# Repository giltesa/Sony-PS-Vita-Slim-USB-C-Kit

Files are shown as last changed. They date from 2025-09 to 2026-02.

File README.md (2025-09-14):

# Sony PS Vita Slim USB-C Kit

The **Sony PS Vita Slim: USB-C Kit** is a board that allows to replace the original charging connector for a modern and standard **USB-C**.

**If your original connector is too old or damaged** and you need a new one, or **if you would like to charge your Sony PS Vita Slim with a standard USB-C charger**, like the charger of your phone, laptop, you can with this board.

This board is compatible with this model:

*   Sony PS Vita Slim

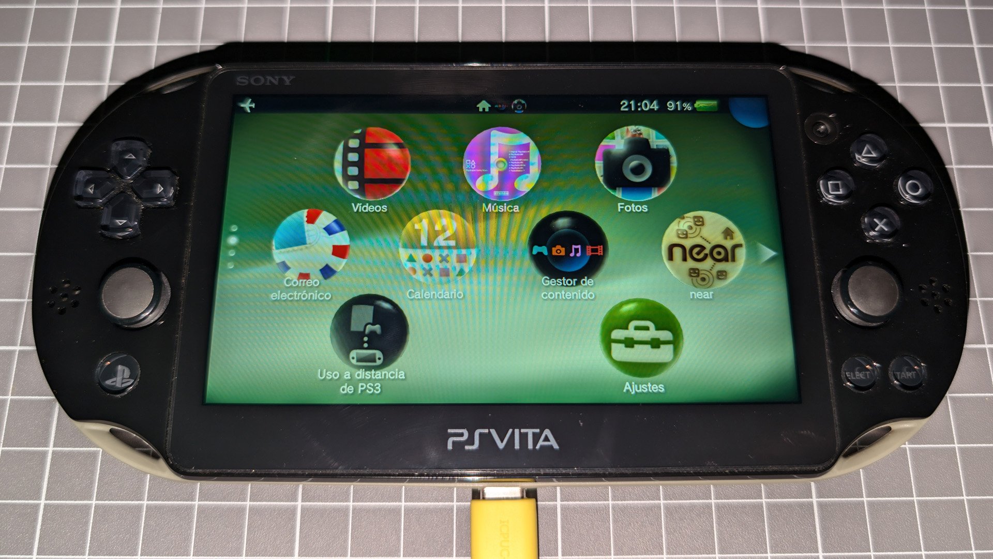
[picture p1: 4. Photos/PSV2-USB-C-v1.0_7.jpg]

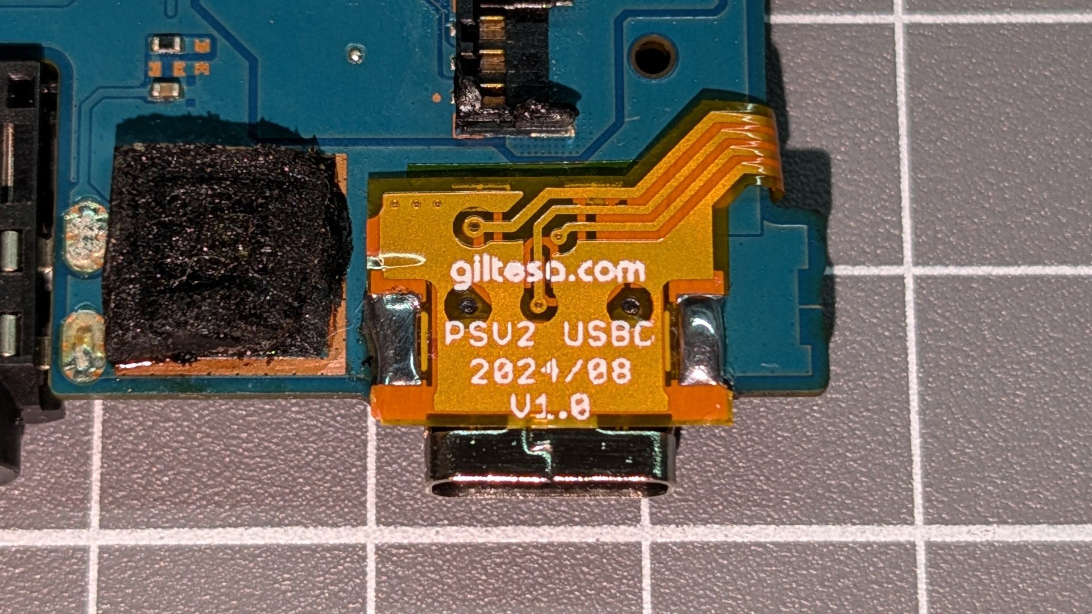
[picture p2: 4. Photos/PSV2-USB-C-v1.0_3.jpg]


## Would you like it?

https://shop.giltesa.com/product/sony-ps-vita-slim-usb-c-kit/

## More

- [giltesa.com](https://giltesa.com "giltesa.com")
- [twitter.com](https://twitter.com/giltesa "twitter.com")

## License

This project is licensed under a **Creative Commons** license:
**[Attribution-NonCommercial-ShareAlike 4.0 International (CC BY-NC-SA 4.0) ](https://creativecommons.org/licenses/by-nc-sa/4.0/)**

Check the [LICENSE.md](LICENSE.md) for more information.

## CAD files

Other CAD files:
2. Renders, 3D models/PCB v1.0.skp
2. Renders, 3D models/PCB v1.2.skp

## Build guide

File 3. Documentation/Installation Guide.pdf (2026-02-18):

# USB-C KIT For

# Sony PS VITA SLIM

### PRODUCT

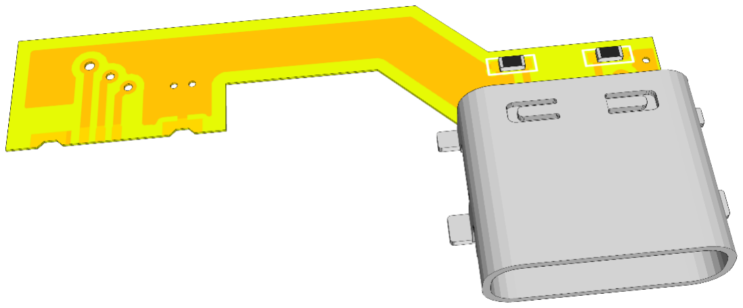
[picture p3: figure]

HTTPS://SHOP.GILTESA.COM/PRODUCT/SONY-PS-VITA-SLIM-USB-C-KIT

# PLEASE READ THROUGH THESE INSTRUCTIONS

ENTIRELY BEFORE ATTEMPTING TO INSTALL.

# WARNING: IF YOU ARE NOT COMFORTABLE WITH SOLDERING, OR PERFORMING ANY STEP IN THIS

GUIDE, DO NOT PERFORM THE INSTALL YOURSELF.

# FIND SOMEONE WHO IS COMFORTABLE TO DO IT FOR

YOU.

INDEX

# Description

The Sony PS Vita Slim: USB-C Kit is a board that allows to replace the original charging connector for a modern and standard USB-C.

If your original connector is too old or damaged and you need a new one, or if you would like to charge your Sony PS Vita Slim with a standard USB-C charger, like the charger of your phone, laptop, you can with this kit.

This board is compatible with this model:

- Sony PS Vita Slim

# FEATURES

- Charging your Sony PS Vita Slim with:
- USB power banks
- USB-A chargers
- USB-C chargers
- USB-C PD chargers (normal speed, not fast)
- USB-A to USB-C cables
- USB-C to USB-C cables
- USB data support.

# INCLUDED

- 1 flexible board.

# Recommended / REQUIRED (NOT INCLUDED)

- Phillips screwdriver.
- Soldering iron / hot-air soldering station.
- USB microscope.
- Kapton tape.
- Tin.
- Flux.
- Desoldering pump.
- Desoldering mesh.
- Metal file.
- Tweezers.
- Isopropyl alcohol.

# Board details

This small flexible board has a total of 9 pads: 5 of them are on the bottom side of the PCB, exactly where the original MicroUSB connector was soldered. The other 4 pads correspond to the USB-C legs. The following explains what each pad is for.

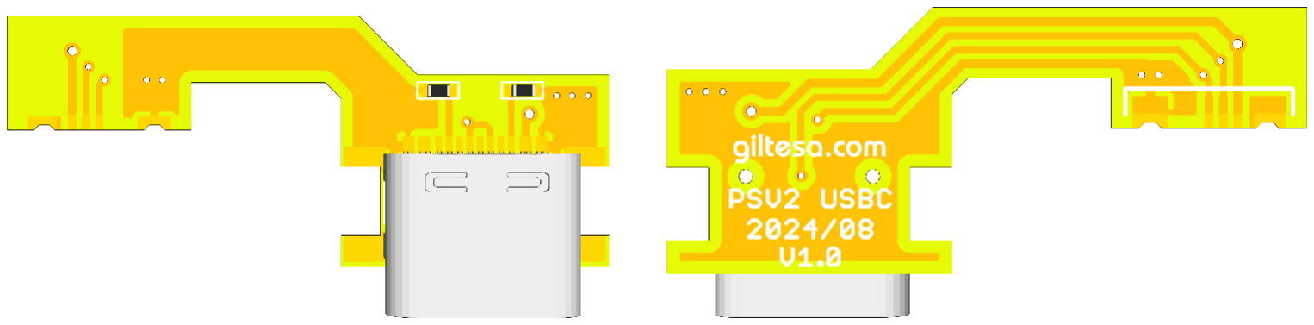
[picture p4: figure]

The pads are, from left to right in the image on the right:

- GND | The ground pad.
- D+ | The positive data line.
- D- | The negative data line.
- VCC | The 5V line from the USB-C.
- ANCHOR | It secures the flex cable to the mainboard.
- USB SHIELD LEGS They secure the board firmly to the mainboard.

# Test the board!

Before starting the installation, you should test the board. If it doesn’t work contact me for a replacement (https://shop.giltesa.com/refund-policy/) (all boards are fully tested, but they may damage during the shipping, we try to package them as better as possible), if it works, go ahead with the installation.

Connect the power from your USB charger to the USB-C connector on the board. Then, with a multimeter in voltage measurement mode, check for a 5V reading. If that's the case, continue with the installation.

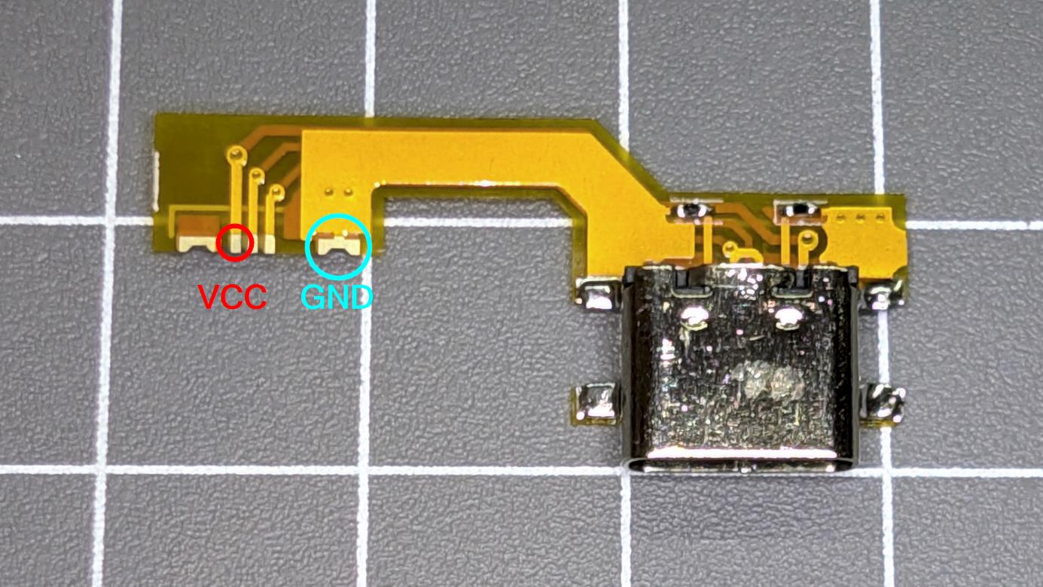
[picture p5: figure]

Unfortunately, it is not possible to test the data connection until the board is fully installed.

# INSTALLATION STEPS

Please, carefully read the following steps for a successful installation.

## Pre installation Steps

Before the installation, your Sony PS Vita Slim may need some extra steps to have it ready for the kit.

1. Disassembly the Sony PS Vita Slim

If the steps in this guide are insufficient and you can't proceed, you can refer to the iFixit guide (https://www.ifixit.com/Guide/PS+Vita+Slim+Motherboard+Replacement/97903) for opening the console.

Sony PS Vita Slim use the phillips screws to close the shell. Remove all the accessories such as the memory card and game card. Then remove the 7 screws which hold the back shell.

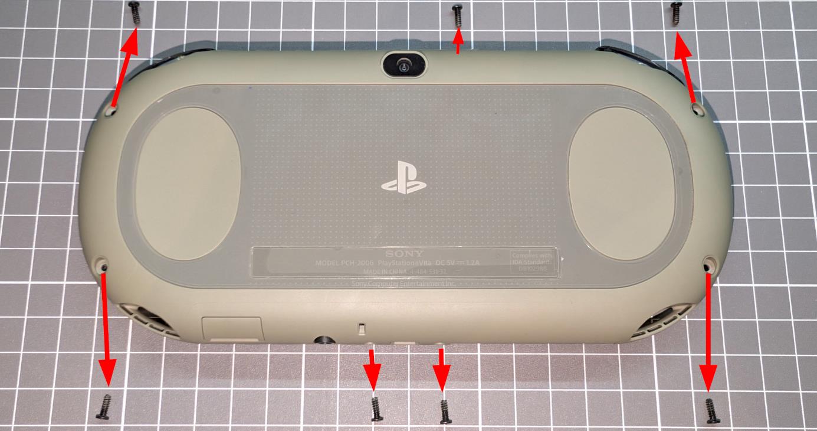
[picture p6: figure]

When removing the cover, do it slowly and carefully, as the rear touch sensor is connected with a flexible cable.

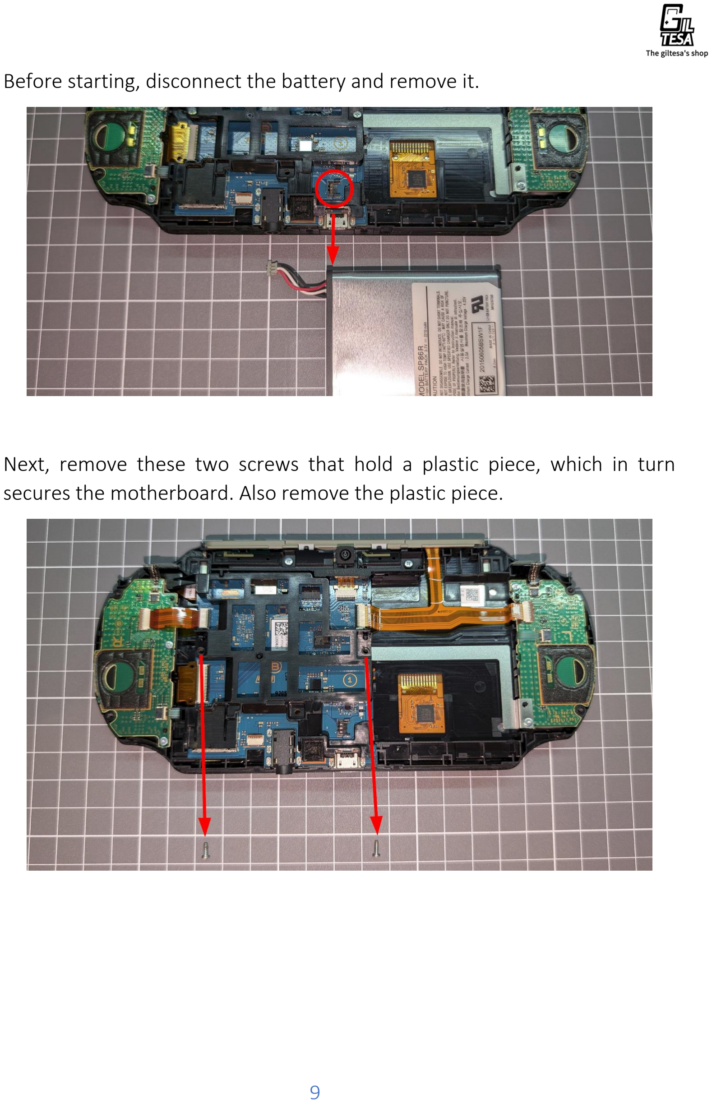
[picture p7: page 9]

Before starting, disconnect the battery and remove it.

Next, remove these two screws that hold a plastic piece, which in turn secures the motherboard. Also remove the plastic piece.

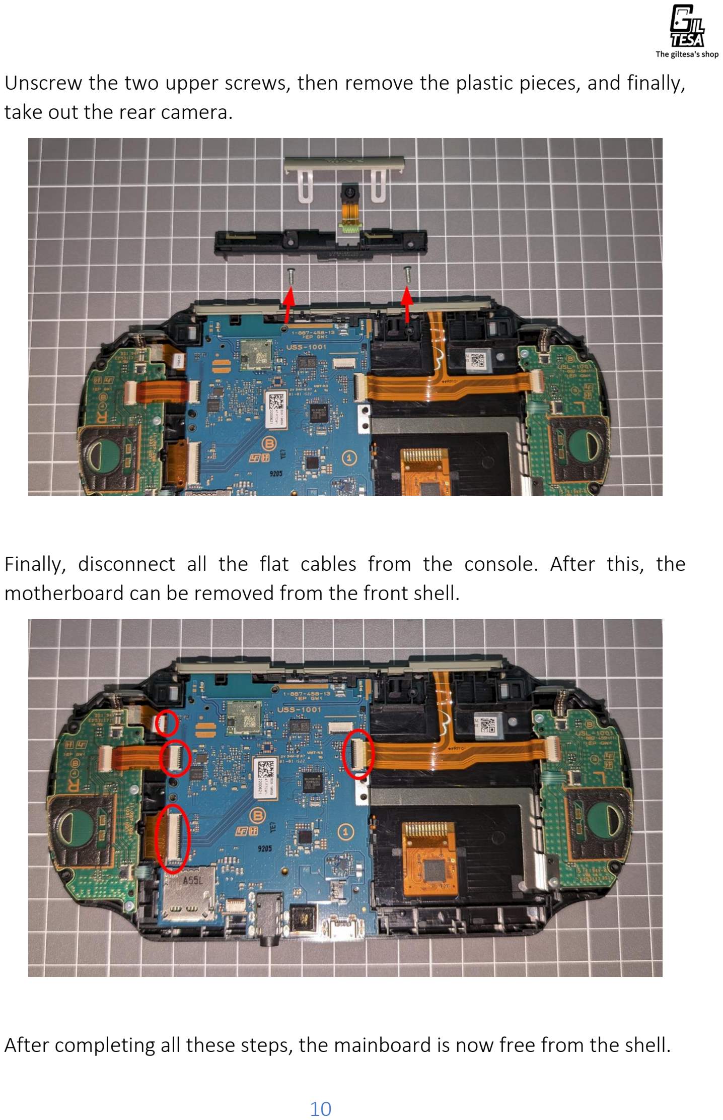
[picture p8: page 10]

Unscrew the two upper screws, then remove the plastic pieces, and finally, take out the rear camera.

Finally, disconnect all the flat cables from the console. After this, the motherboard can be removed from the front shell.

After completing all these steps, the mainboard is now free from the shell.

## installation Steps

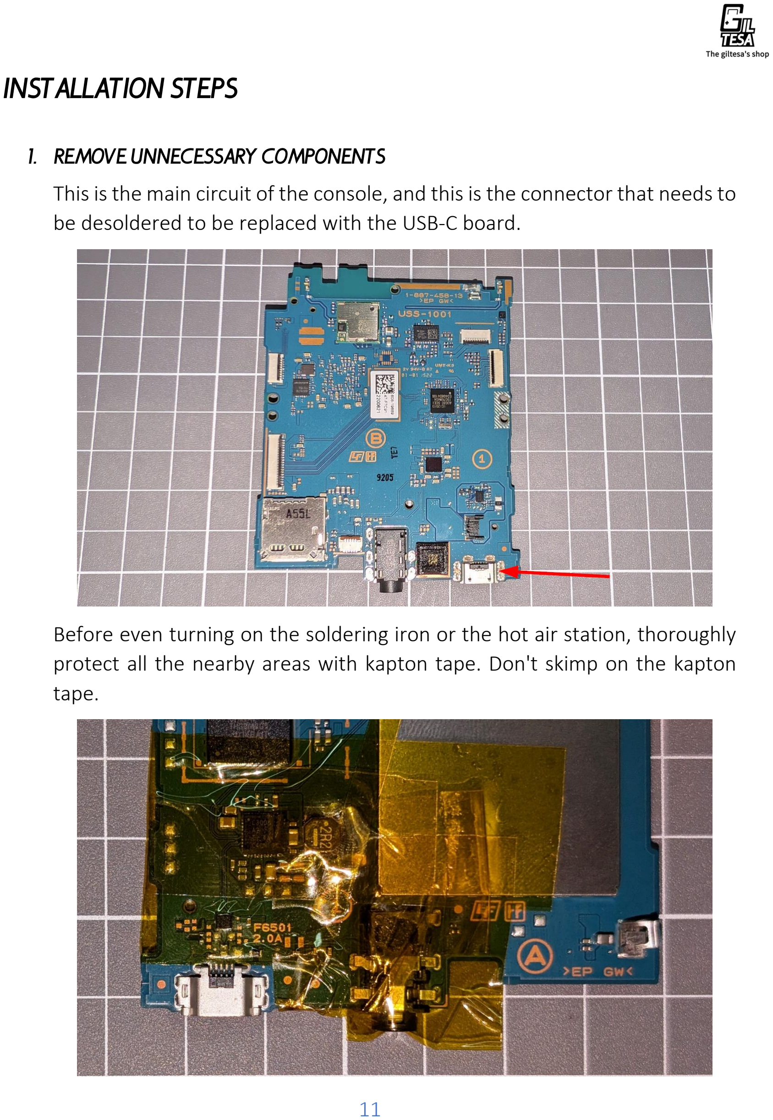
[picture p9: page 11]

1. Remove unnecessary components

This is the main circuit of the console, and this is the connector that needs to be desoldered to be replaced with the USB-C board.

Before even turning on the soldering iron or the hot air station, thoroughly protect all the nearby areas with kapton tape. Don't skimp on the kapton tape.

Now, remove the connector. This can be challenging because the six legs of the connector's housing are firmly attached to the mainboard. Additionally, the ground plane is very large, causing heat to dissipate quickly.

Apply flux and desolder each leg one by one. You can also add higher-quality solder to mix with the existing solder, which will help you remove it all more easily.

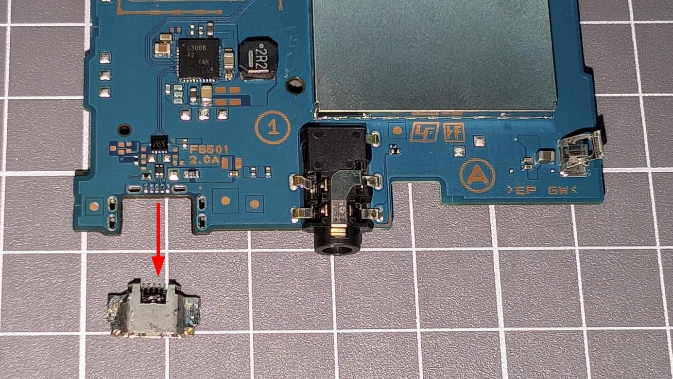
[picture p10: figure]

Remove the solder from the pins, ensuring they are not bridged together. It's not necessary to remove the solder from the four holes where the connector was soldered but try to ensure that the solder/pads are completely flat.

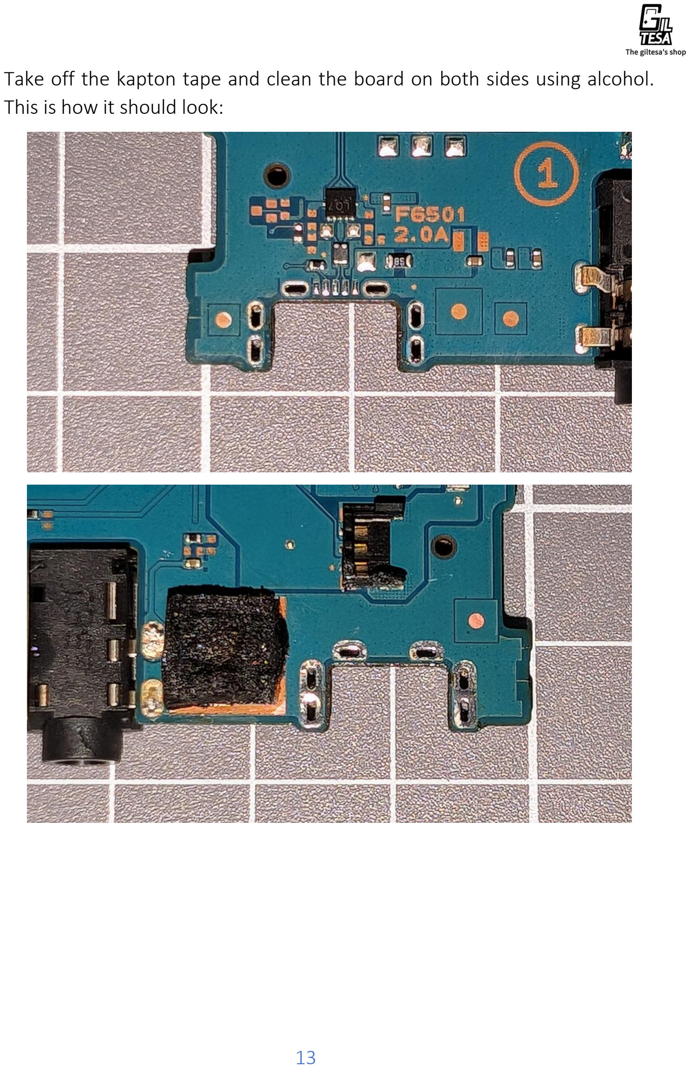
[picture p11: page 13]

Take off the kapton tape and clean the board on both sides using alcohol. This is how it should look:

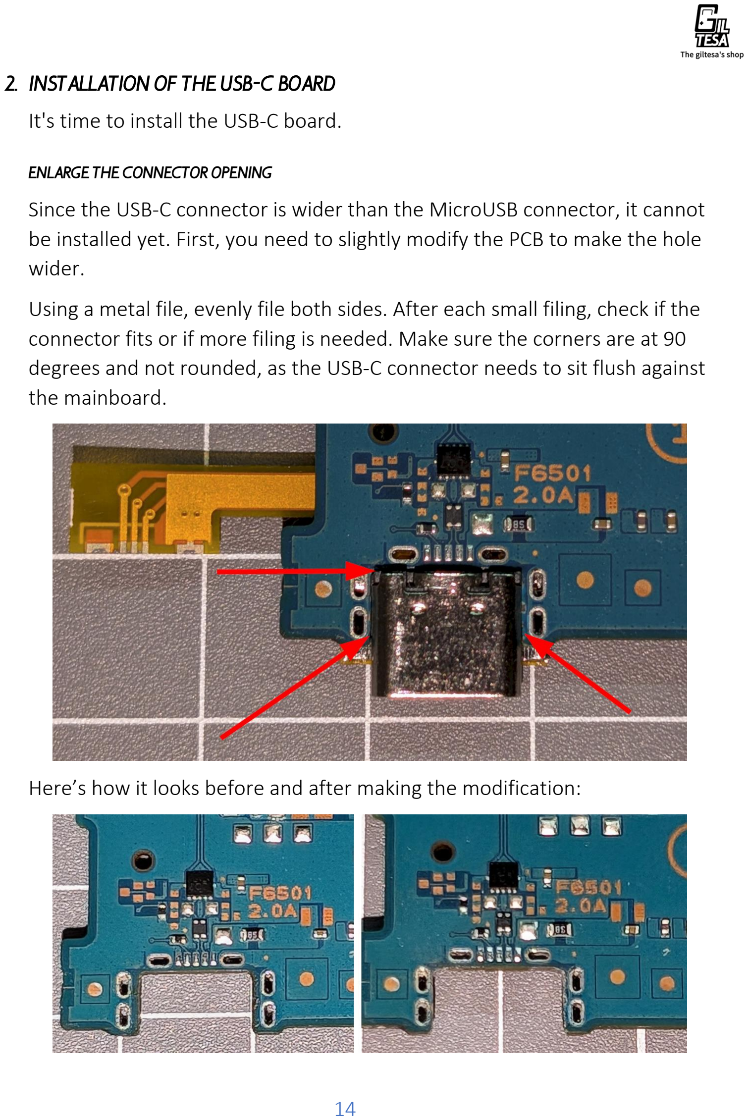
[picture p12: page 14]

2. Installation of the USB-C board

It's time to install the USB-C board.

ENLARGE THE CONNECTOR OPENING
Since the USB-C connector is wider than the MicroUSB connector, it cannot be installed yet. First, you need to slightly modify the PCB to make the hole wider.

Using a metal file, evenly file both sides. After each small filing, check if the connector fits or if more filing is needed. Make sure the corners are at 90 degrees and not rounded, as the USB-C connector needs to sit flush against the mainboard.

Here’s how it looks before and after making the modification:

SOLDERING THE FLAT CABLE
Before soldering the cable, first protect this area with kapton tape. This will prevent the solder from seeping into this side of the PCB. Additionally, the USB-C pins will later touch this area, and without the kapton tape, there could be a short circuit.

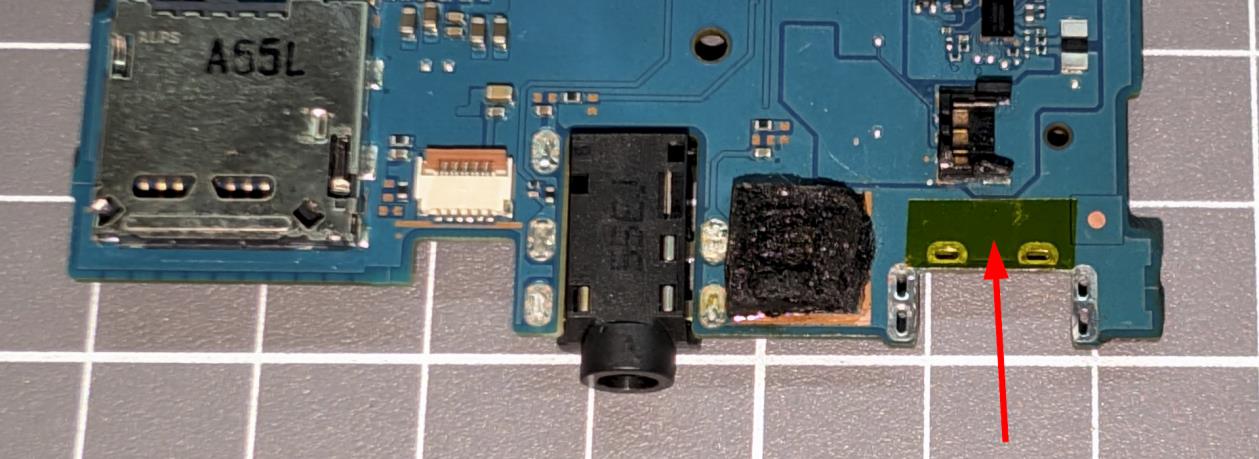
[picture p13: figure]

Then, you need to solder the flat cable or flexible PCB from the kit. It should be positioned exactly where the original MicroUSB connector was located.

NOTE: If you tin all the pads on the flexible PCB on both sides first, by applying flux and then solder, it’ll be easier to solder the cable to the mainboard later.

Start by soldering the large pad on the right. At the same time, make sure the rest of the pads are perfectly aligned with the pads on the mainboard.

Once all the pads are aligned, solder the large pad on the left. Finally, solder the central pads. It should look something like this:

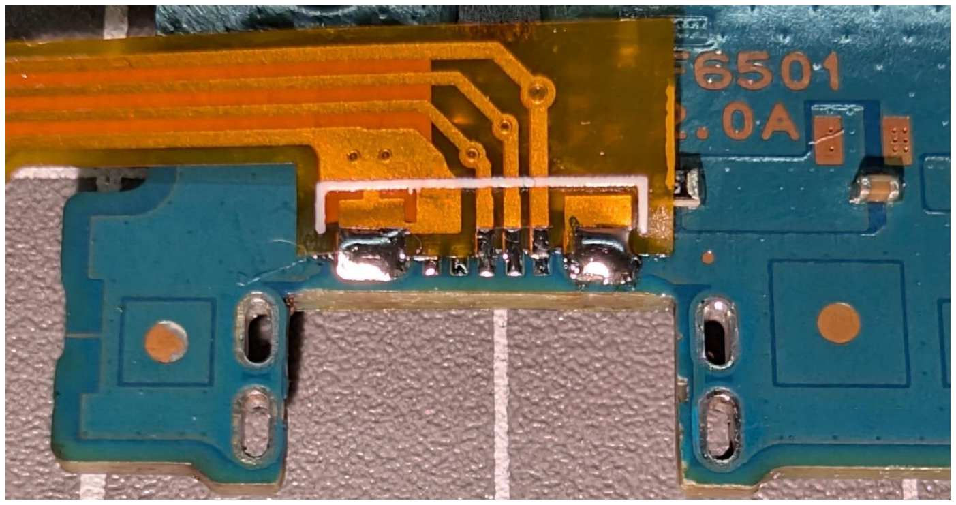
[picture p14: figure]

Although the two large pads on each side hold the cable firmly, you can add some kapton tape for extra security if you wish.

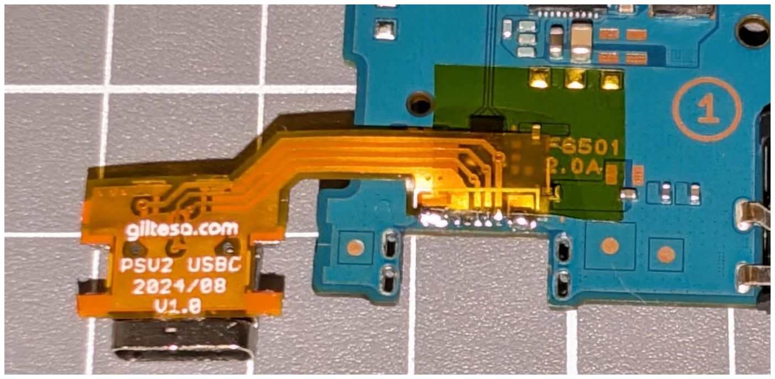
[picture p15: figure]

CONNECTION TEST
Before proceeding to the next step, it is advisable to use a multimeter to check that all connections are properly made.

You can even partially reassemble the console to ensure it charges the battery and allows data transfer from the PC.

Do it now, because once the USB-C is fully soldered, the area will have almost no access.

SOLDERING THE USB-C CONNECTOR LEGS
Fold the flexible circuit over the mainboard and place it in the hole as shown in the picture. The four legs of the USB-C shield need to be soldered to the mainboard.

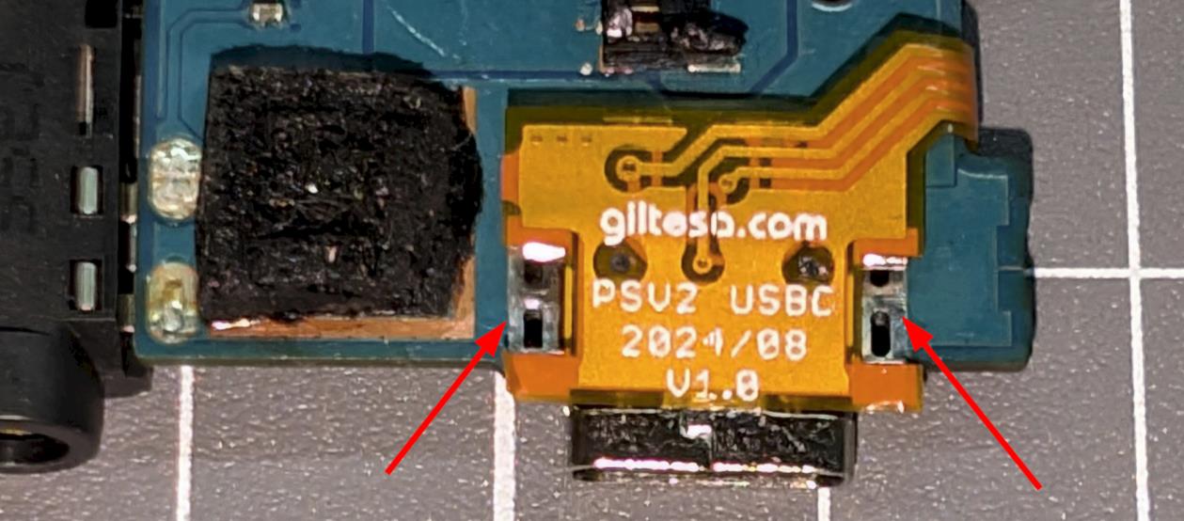
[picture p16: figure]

Make sure to heat the pads on the mainboard sufficiently so that the solder forms a strong bond. Keep in mind that the ground plane (copper surface) connected to those pads is very large, which causes the heat from the soldering iron to dissipate quickly.

It is crucial that the soldering is done properly, as it is the only thing that will secure the new connector to the mainboard.

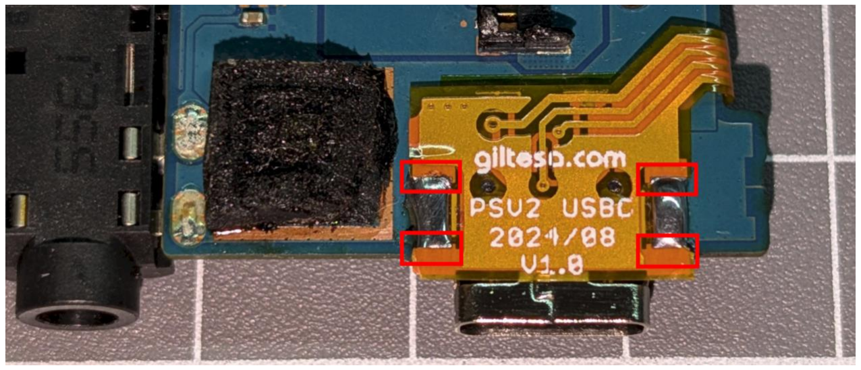
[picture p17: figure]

IMPORTANT NOTE: Make sure the legs of the USB-C are as close to the mainboard as possible.

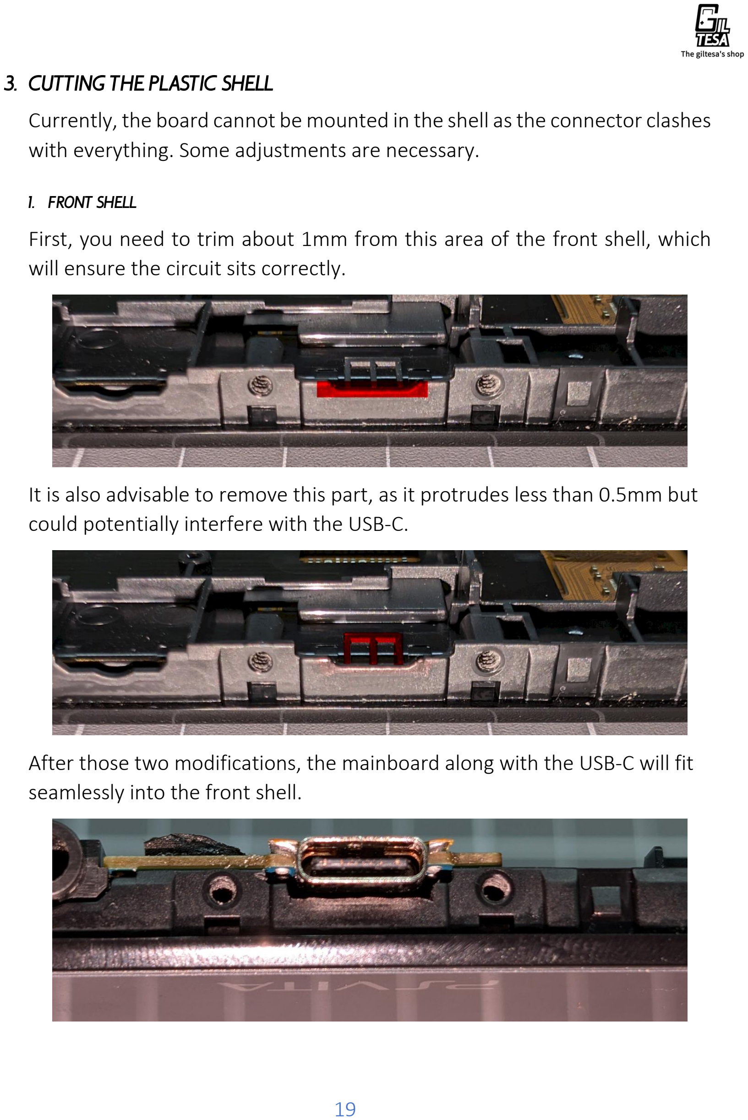
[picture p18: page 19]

3. Cutting the plastic shell

Currently, the board cannot be mounted in the shell as the connector clashes with everything. Some adjustments are necessary.

1. FRONT SHELL
First, you need to trim about 1mm from this area of the front shell, which will ensure the circuit sits correctly.

It is also advisable to remove this part, as it protrudes less than 0.5mm but could potentially interfere with the USB-C.

After those two modifications, the mainboard along with the USB-C will fit seamlessly into the front shell.

2. BACK SHELL
Here are two parts that need to be trimmed; let's start with the easy one. You need to remove 1mm of depth from this entire area of plastic.

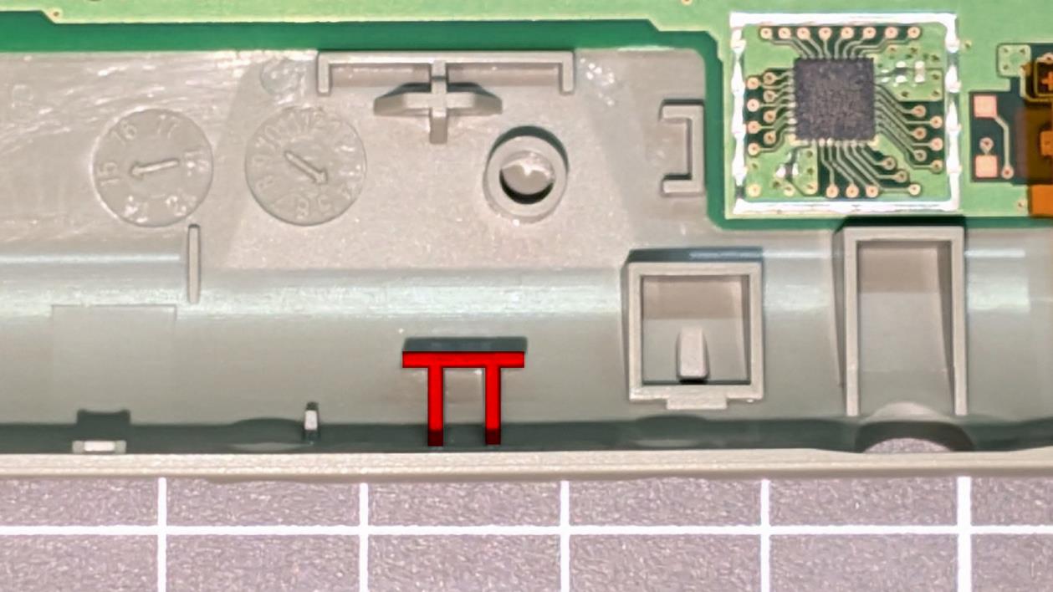
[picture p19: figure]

As for the complicated part, it's the hole where the USB-C connector protrudes. The new connector is significantly larger than the original one and needs to pass completely through the casing from the inside to the outside, as it is also longer.

Enlarge the hole using a fine-tipped cutter, metal files, or any other tool you have available. Preferably use a non-electric tool to avoid melting the plastic.

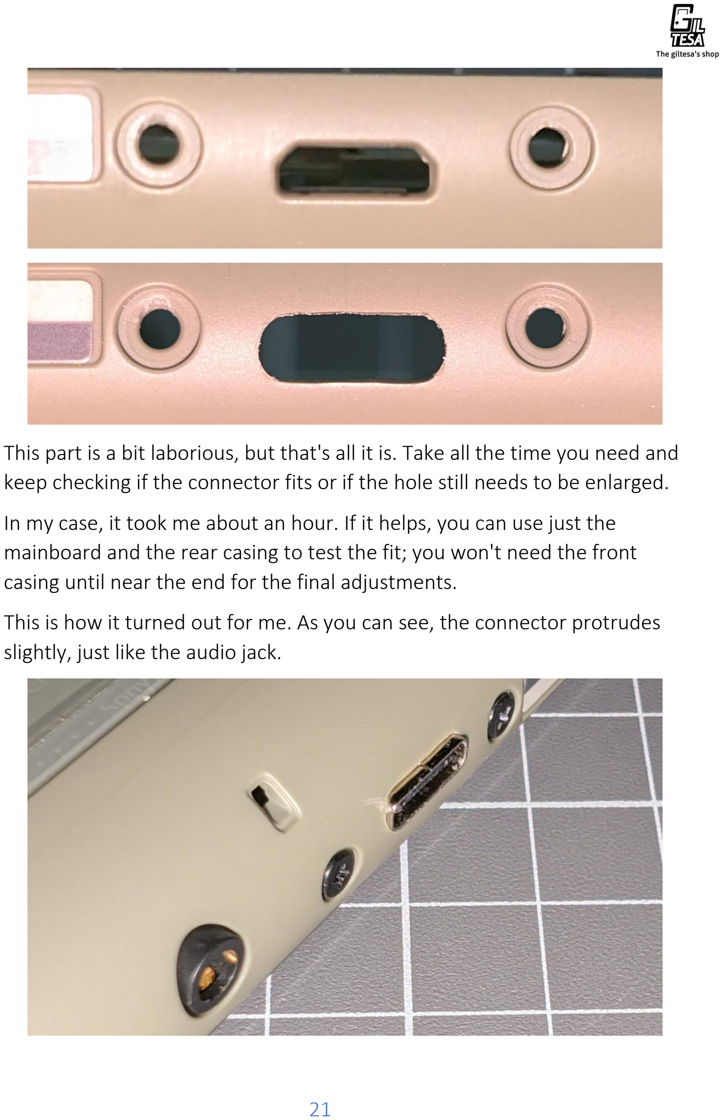
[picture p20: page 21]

This part is a bit laborious, but that's all it is. Take all the time you need and keep checking if the connector fits or if the hole still needs to be enlarged.

In my case, it took me about an hour. If it helps, you can use just the mainboard and the rear casing to test the fit; you won't need the front casing until near the end for the final adjustments.

This is how it turned out for me. As you can see, the connector protrudes slightly, just like the audio jack.

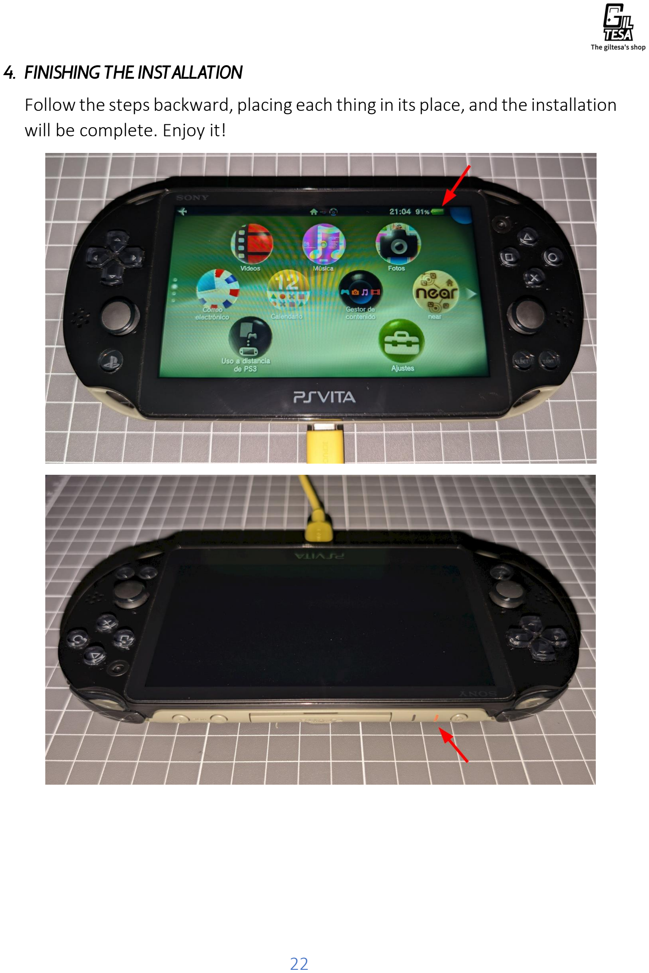
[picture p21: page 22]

4. Finishing the installation

Follow the steps backward, placing each thing in its place, and the installation will be complete. Enjoy it!

# Frequently Asked Questions - FAQ

What charger can be used?
You can use any standard charger for mobile phones, computers, etc., with 5V 1A. It doesn't need to be a Power Delivery charger since this feature is not used. Of course, if you want to use a Power Delivery charger, there's no problem or risk.

Technical data for curious minds:

Power Delivery chargers can supply a wide range of voltages: 5V, 9V, 12V, 15V, and 20V. However, for this to happen, the device must communicate with the charger to explicitly request the desired voltage. Without this communication, the charger will never supply more than 5V. That's one of the advantages of USB-C, as it can be used with both old and modern devices.

I damaged the pads removing the original connector. Can it be fixed?
You can try soldering each flexible cable pad to the following alternative points on the mainboard shown in the image below. (At the beginning of the installation guide, each pad of the kit is indicated)

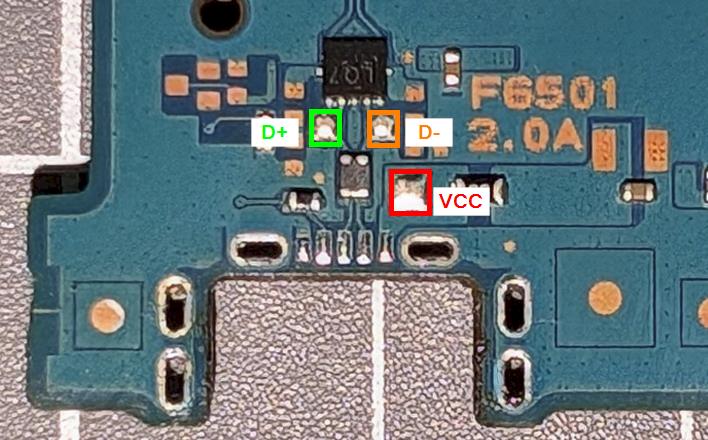
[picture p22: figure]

Is it possible to output audio through a USB-C connection?
It’s not possible. The USB-C board doesn’t add any new functionality. The connector doesn’t provide power output, only input, so it can’t power the headphones and their internal DAC. Additionally, the console isn’t programmed to output audio through.
